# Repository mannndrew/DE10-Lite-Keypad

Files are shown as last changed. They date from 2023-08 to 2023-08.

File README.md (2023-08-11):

# DE10-Lite Keypad

A modern design on a PCB keypad with KiCad to be used on the DE10-Lite FPGA or with other similar device pin headers including the Arduino UNO R3.

---

## Repository Structure
The repository is organized as follows:

- `Documentation/`: Holds images and visual assets related to the project.
- `Keypad/`: Includes KiCad project files.
- `PCBWay/`: Contains assembly instructions and pricing documentation.

---

## Schematic

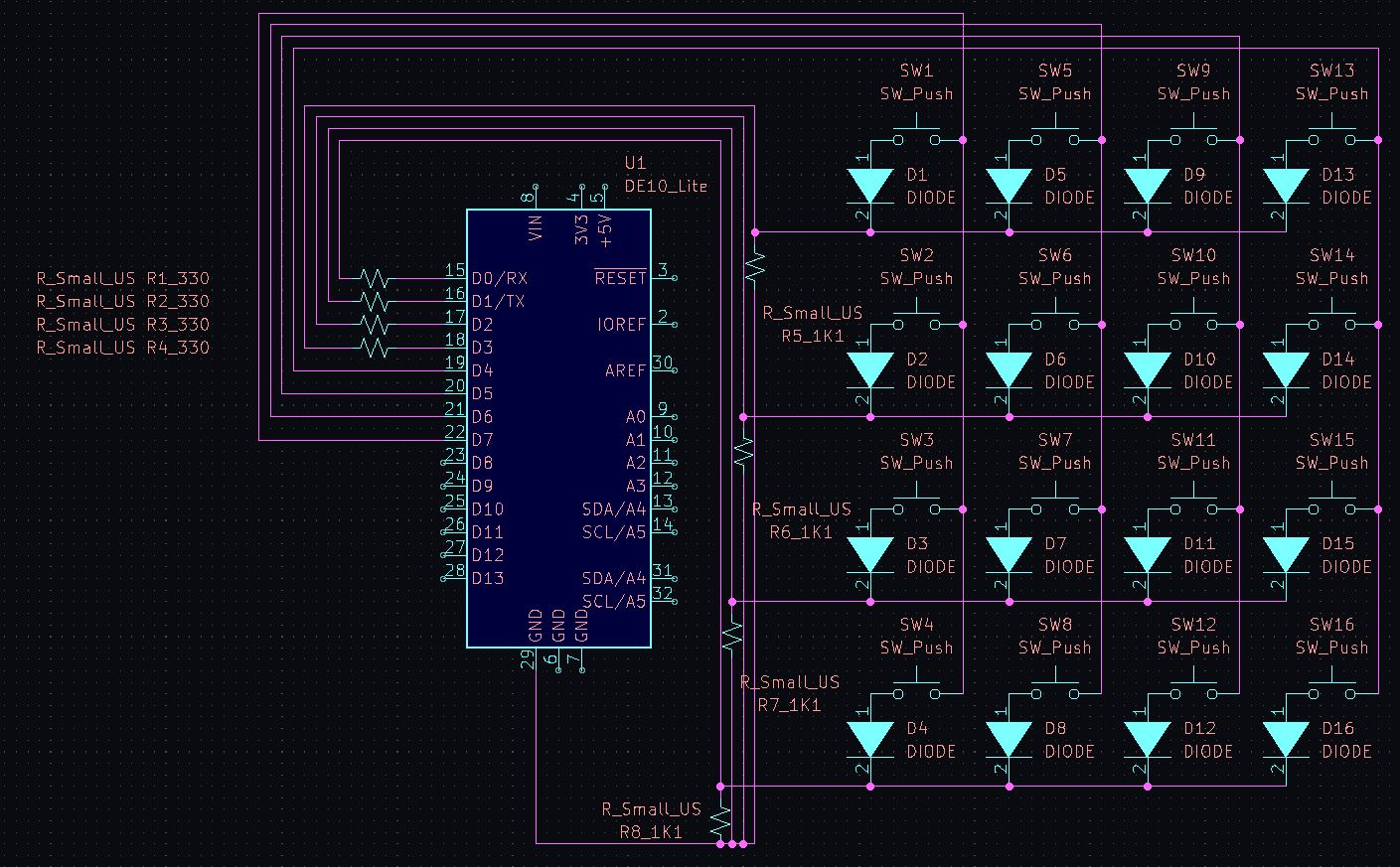
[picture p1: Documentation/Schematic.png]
 

---

## PCB

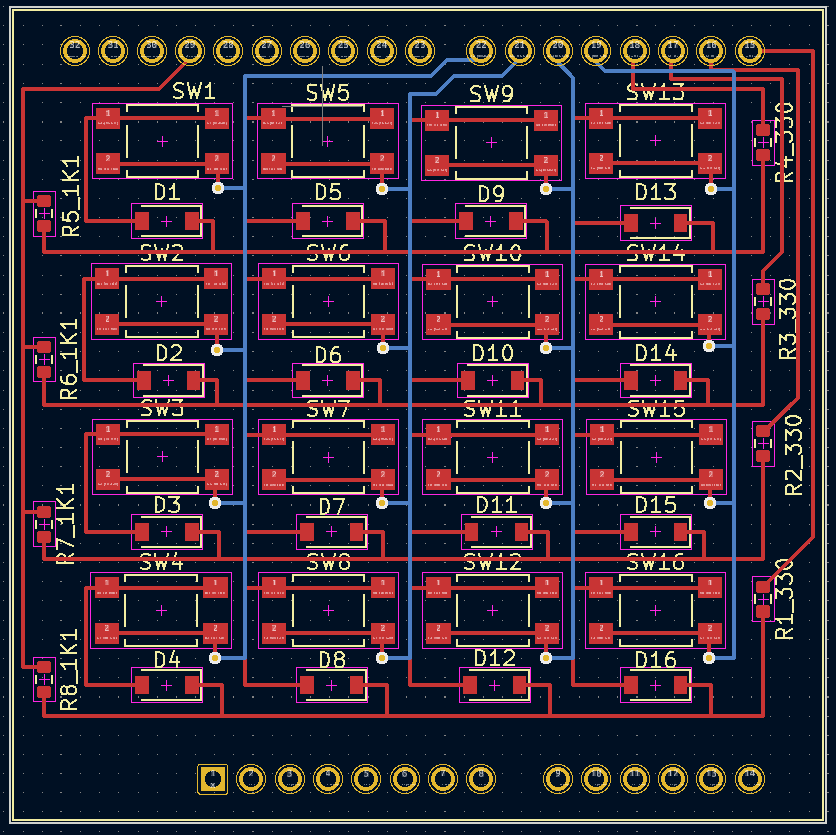
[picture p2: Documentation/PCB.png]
 

---

## 3D Model

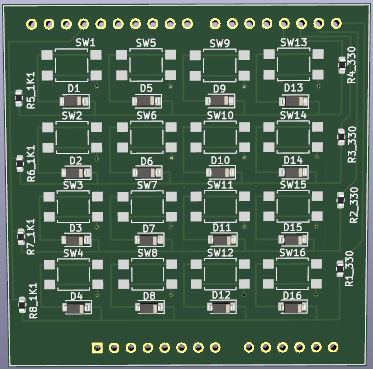
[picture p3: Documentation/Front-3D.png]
 
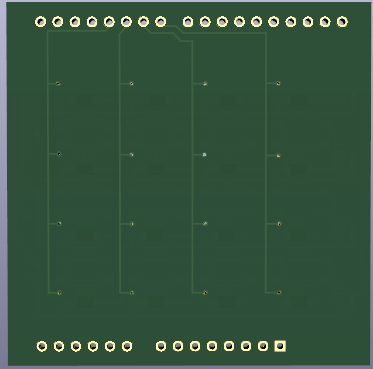
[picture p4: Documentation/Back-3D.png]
 

---

## License
This is published under the [MIT License](https://opensource.org/licenses/MIT).

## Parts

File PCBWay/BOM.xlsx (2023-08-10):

Item # | *Designator | *Qty | Manufacturer | *Mfg Part # | Description / Value | *Package/Footprint | Type | Your Instructions / Notes
1 | D2,D4,D15,D9,D1,D13,D7,D5,D3,D12,D16,D6,D10,D8,D11,D14 | 160 | Diodes Incorporated | MMSZ5231B-7-F | DIODE ZENER 5.1V 500MW SOD123 | D_SOD-123 | SMD
2 | R1_33, R2_330, R3_330, R4_330 | 40 | Bourns Inc. | CR0603-JW-331ELF | RES SMD 330 OHM 5% 1/10W 0603 | R_0603_1608 | SMD
3 | R5_1K1, R6_1K1, R7_1K1, R8_1K1 | 40 | Bourns Inc. | CR0603-JW-102ELF | RES SMD 1K OHM 5% 1/10W 0603 | R_0603_1608 | SMD
4 | SW10,SW2,SW15,SW14,SW8,SW7,SW13,SW6,SW11,SW12,SW5,SW9,SW16,SW1,SW3,SW4 | 160 | E-Switch | TL3305BF160QG | SWITCH TACTILE SPST-NO 50MA 12V | TL3305 | SMD
5 | Pin Header | 40 | Amphenol ICC (FCI) | 10129378-910003BLF | CONN HEADER VERT 10POS 2.54MM | 2.54mm | thru-hole | Solder on to each pin header strip

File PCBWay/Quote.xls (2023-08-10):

PCBWay Bom Quotation, Product No.:T-B11W516502A
Item # | *Designator | *Qty | Manufacturer | *Mfg Part # | Description / Value | *Package/Footprint | Mounting Type | Your Instructions / Notes | *Unit Price(10 sets) | *Total | *Delivery Time | *PCBWay Note | Customer Reply | PCBWay Update
1 | D2,D4,D15,D9,D1,D13,D7,D5,D3,D12,D16,D6,D10,D8,D11,D14 | 160 | Diodes Incorporated | 1N4148W-7-F | DIODE GEN PURP 100V 300MA SOD123 | D_SOD-123 | SMD |  | $0.022 | $3.520 |  | QTY for 1board or 10boards? | QTY is for all 10 boards
2 | R1_33, R2_330, R3_330, R4_330 | 40 | Bourns Inc. | CR0603-JW-331ELF | RES SMD 330 OHM 5% 1/10W 0603 | R_0603_1608 | SMD |  | $0.005 | $0.200 |  | QTY for 1board or 10boards? | QTY is for all 10 boards
3 | R5_1K1, R6_1K1, R7_1K1, R8_1K1 | 40 | Bourns Inc. | CR0603-JW-102ELF | RES SMD 1K OHM 5% 1/10W 0603 | R_0603_1608 | SMD |  | $0.008 | $0.320 |  | QTY for 1board or 10boards? | QTY is for all 10 boards
4 | SW10,SW2,SW15,SW14,SW8,SW7,SW13,SW6,SW11,SW12,SW5,SW9,SW16,SW1,SW3,SW4 | 160 | E-Switch | TL3305BF160QG | SWITCH TACTILE SPST-NO 50MA 12V | TL3305 | SMD |  | $0.216 | $34.560 |  | QTY for 1board or 10boards? | QTY is for all 10 boards
5 | Pin Header | 40 | Amphenol ICC (FCI) | 10129378-910003BLF | CONN HEADER VERT 10POS 2.54MM | 2.54mm | thru-hole | Solder on to each pin header strip | $0.225 | $9.000 |  | QTY for 1board or 10boards? | QTY is for all 10 boards
 |  |  |  |  |  |  |  |  | Component Cost | $47.60

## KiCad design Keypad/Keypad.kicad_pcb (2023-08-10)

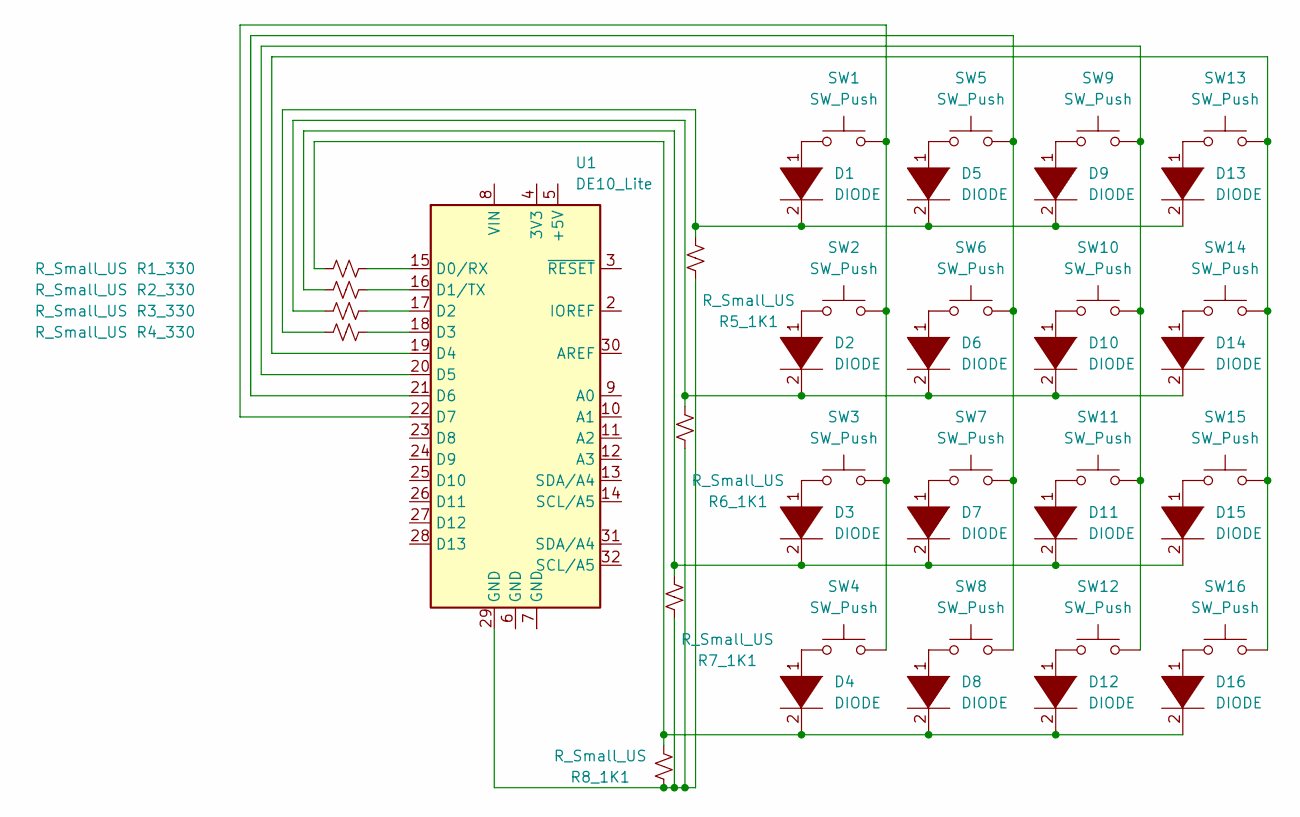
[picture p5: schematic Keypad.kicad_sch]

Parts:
D1, D2, D3, D4, D5, D6, D7, D8, D9, D10, D11, D12, D13, D14, D15, D16: DIODE; D_SOD-123
R1_330, R2_330, R3_330, R4_330, R5_1K1, R6_1K1, R7_1K1, R8_1K1: R_Small_US; R_0603_1608Metric
SW1, SW2, SW3, SW4, SW5, SW6, SW7, SW8, SW9, SW10, SW11, SW12, SW13, SW14, SW15, SW16: SW_Push; SW_SPST_TL3305B
U1: DE10_Lite

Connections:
unnamed: D1.1 (K), SW1.1
unnamed: D1.2 (A), D5.2 (A), D9.2 (A), D13.2 (A), R4_330.2, R5_1K1.2
unnamed: D2.1 (K), SW2.1
unnamed: D3.1 (K), SW3.1
unnamed: D4.1 (K), SW4.1
unnamed: D5.1 (K), SW5.1
unnamed: D6.1 (K), SW6.1
unnamed: D7.1 (K), SW7.1
unnamed: D8.1 (K), SW8.1
unnamed: D9.1 (K), SW9.1
unnamed: D10.1 (K), SW10.1
unnamed: D2.2 (A), D6.2 (A), D10.2 (A), D14.2 (A), R3_330.2, R6_1K1.2
unnamed: D11.1 (K), SW11.1
unnamed: D3.2 (A), D7.2 (A), D11.2 (A), D15.2 (A), R2_330.2, R7_1K1.2
unnamed: D12.1 (K), SW12.1
unnamed: D4.2 (A), D8.2 (A), D12.2 (A), D16.2 (A), R1_330.2, R8_1K1.2
unnamed: D13.1 (K), SW13.1
unnamed: D14.1 (K), SW14.1
unnamed: D15.1 (K), SW15.1
unnamed: D16.1 (K), SW16.1
unnamed: R1_330.1, U1.15 (D0/RX)
unnamed: R2_330.1, U1.16 (D1/TX)
unnamed: R3_330.1, U1.17 (D2)
unnamed: R4_330.1, U1.18 (D3)
unnamed: R5_1K1.1, R6_1K1.1, R7_1K1.1, R8_1K1.1, U1.29 (GND)
unnamed: SW1.2, SW2.2, SW3.2, SW4.2, U1.22 (D7)
unnamed: SW5.2, SW6.2, SW7.2, SW8.2, U1.21 (D6)
unnamed: SW9.2, SW10.2, SW11.2, SW12.2, U1.20 (D5)
unnamed: SW13.2, SW14.2, SW15.2, SW16.2, U1.19 (D4)

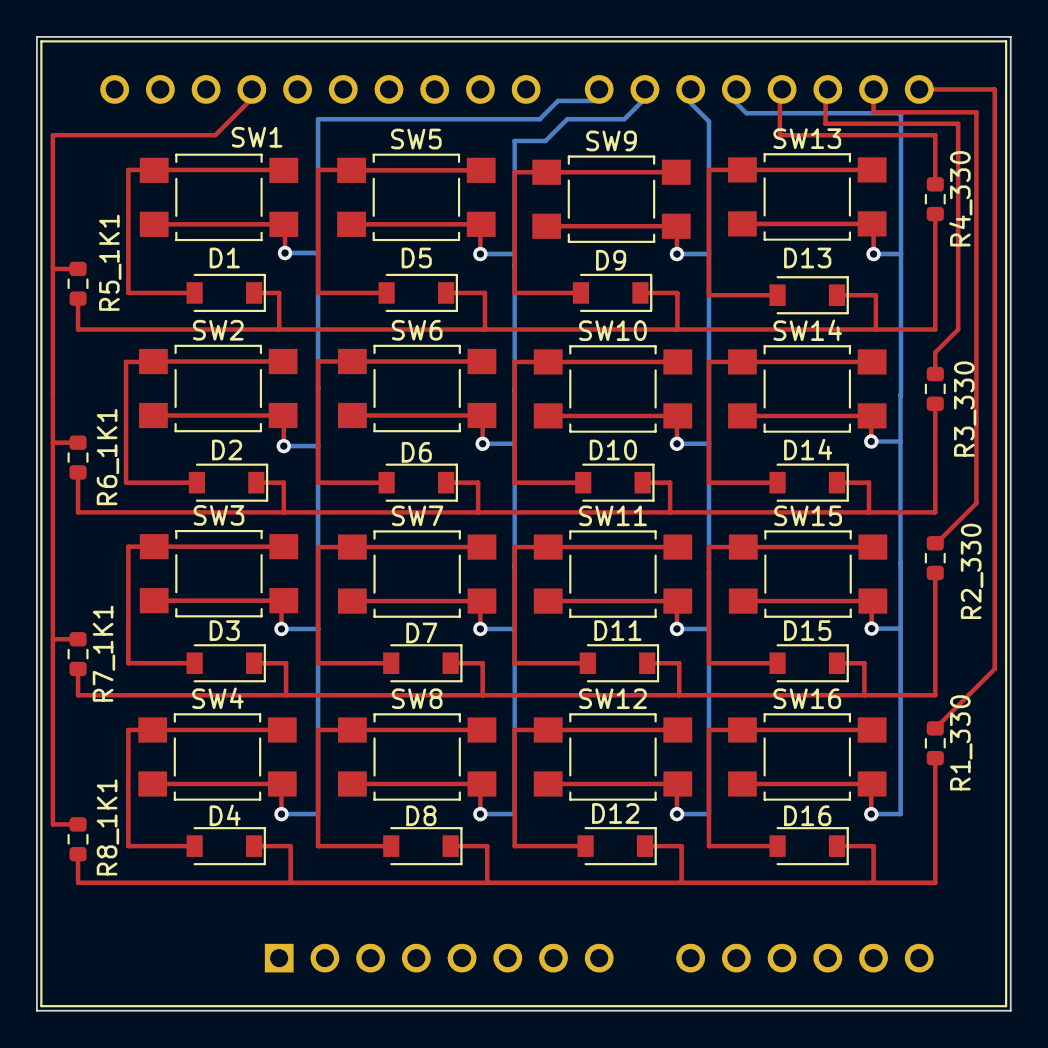
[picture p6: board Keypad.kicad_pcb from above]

Board: 2 copper layers, 54.1 x 54.1 mm, 41 parts (0 on the bottom side), 29 nets.

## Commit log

2023-08-09 Working on de10lite keypad 2.0
    [Keypad-B_Cu.gbr, Keypad-B_Mask.gbr, Keypad-B_Paste.gbr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]
2023-08-10 Added in assembly and product files for PCBWay
    [BOM.xlsx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]
2023-08-10 Added the quote for BOM
    [Quote.xls]
